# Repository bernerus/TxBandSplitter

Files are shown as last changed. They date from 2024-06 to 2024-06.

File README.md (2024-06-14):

# TxBandSplitter
SDR Transmit band splitter and amplifier for VHF/UHF bands. A KiCad + Python project.

The aim of this project is to create an intermediate transmit driver stage that 
takes the RF level of an SDR transmitter from around 1 dBm to around +30 dBm.
Doing this would probably be illegal except for licensed radio amateurs, but
such equipment should nevertheless work only on the amateur bands.
This device takes 1 dBm RF from e.g. a HackRF transceiver, splits the output on
either the 50, 144, 432 och 1295 MHz bands and takes the output level to about +30 dBm or 1 W.
The amplification is done in two steps with the filtering and a programmable attenuator in between,
The final RF is the again split on 4 outputs usein PIN diodes.

The band selection, amplifier power and level of attenuation is controlled over an I2C connection
suitable for connectiong to a RaspBerry PI computer.

Sample software for controlling the device from an RPI is written in Python.

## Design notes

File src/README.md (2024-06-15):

This is the code used for controlling the TxBandSplitter version 3. 

Note that the hardware published in this repo is version 4. 
This means that all definitions here relating to 
Points to review is the defs in p21_defs.py, the band switching codes and the band order for attenuation values.

The code will be reviewes at a later stage when v4 of the hardware 
has been physically realized and tested.

SM6FBQ 2024-06-15

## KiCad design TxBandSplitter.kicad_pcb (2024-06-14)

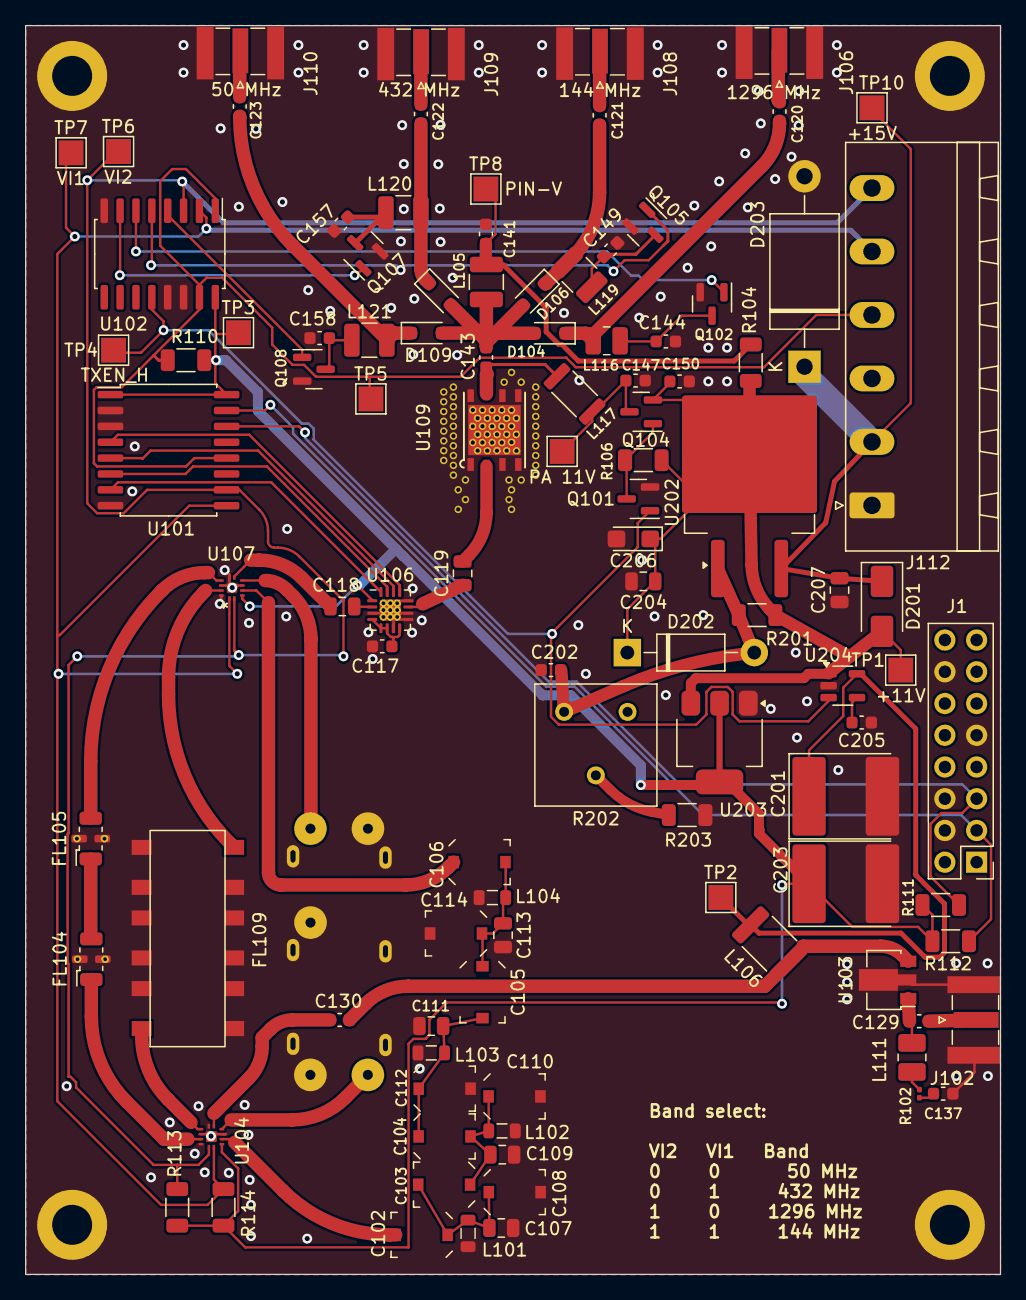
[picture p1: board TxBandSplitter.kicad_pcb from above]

Board: 2 copper layers, 78.0 x 99.9 mm, 109 parts (1 on the bottom side), 63 nets.

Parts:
C102, C106, C108, C110, C112, C114: 5-20pF; C_Trimmer_Murata_TZC3
C103, C104, C105: 2.5-6pF; C_Trimmer_Murata_TZC3
C107, C113: 100pF; C_0805_2012Metric
C109, C111: 120pF; C_0805_2012Metric
C117, C120, C121: 1nF; C_0603_1608Metric
C118, C119: 1nF; C_0805_2012Metric
C122, C123, C129, C130, C141, C143, C144, C147, C149, C150, C157, C158, C205: 10nF; C_0603_1608Metric
C137: 330pF; C_0603_1608Metric
C201: 2.2μF; CP_EIA-7260-38_AVX-R_Pad2.68x6.30mm_HandSolder
C202: 10μF; C_0603_1608Metric
C203: 10μF; CP_EIA-7260-38_AVX-R_Pad2.68x6.30mm_HandSolder
C204, C207: 0.1μF; C_0805_2012Metric
C206: 1μF 16V Tantal; CP_EIA-3216-18_Kemet-A
D104, D106, D107, D109: BA592; D_SOD-323_HandSoldering
D201: LL4002; D_SMA
D202: LL4002; D_DO-41_SOD81_P10.16mm_Horizontal
D203: 1.5KE18A; D_DO-201AE_P15.24mm_Horizontal
FL101: FE-7H3-160A; FE-7H3-160
FL104: HFCN-1200+; Filter_Mini-Circuits_FV1206
FL105: LFCN-1325; Filter_Mini-Circuits_FV1206
FL109: FE-1069; 5CHT
H101, H102, H103, H104: MountingHole_Pad; MountingHole_3.2mm_M3_DIN965_Pad
J1: Raspberry_Pi 16-pin; PinHeader_2x08_P2.54mm_Vertical
J102, J106, J108, J109, J110: SMA; SMA_Samtec_SMA-J-P-X-ST-EM1_EdgeMount
J112: Conn_01x06_Pin; PhoenixContact_MSTBA_2,5_6-G-5,08_1x06_P5.08mm_Horizontal
L101, L102, L103, L104: 68 nH; L_0805_2012Metric
L105: 5.6uH; L_1210_3225Metric
L106, L117: WA8514-AE; L_1812_4532Metric
L111: 680nH; L_1008_2520Metric_Pad1.43x2.20mm_HandSolder
L116: 680 nH; L_1008_2520Metric
L119: 1.8uH; L_1210_3225Metric
L120: 5,6 uH; L_1210_3225Metric
L121: 15 uH; L_1210_3225Metric
Q101, Q102, Q105, Q107, Q108: BSS138; SOT-23
Q104: FDN358P; SOT-23
R102: 150; R_0201_0603Metric
R104: 270; R_1206_3216Metric
R106, R110, R111, R112, R113, R114: 10k; R_1206_3216Metric
R201, R203: 220; R_1206_3216Metric
R202: 1k; Potentiometer_Bourns_3386F_Vertical
TP1: +11V; TestPoint_Pad_2.0x2.0mm
TP2: VCC; TestPoint_Pad_2.0x2.0mm
TP3: VDD; TestPoint_Pad_2.0x2.0mm
TP4: TXEN_H; TestPoint_Pad_2.0x2.0mm
TP5: TXEN_L; TestPoint_Pad_2.0x2.0mm
TP6: VI2; TestPoint_Pad_2.0x2.0mm
TP7: VI1; TestPoint_Pad_2.0x2.0mm
TP8: PIN-V; TestPoint_Pad_2.0x2.0mm
TP9: PA 11V; TestPoint_Pad_2.0x2.0mm
TP10: +15V; TestPoint_Pad_2.0x2.0mm
U101: PCF8574; SOIC-16W_7.5x10.3mm_P1.27mm
U102: 4555; SO-16_5.3x10.2mm_P1.27mm
U103: PGA-103+; SOT-89-3
U104, U107: RFSW6042; QFN12_RFSW_QOR
U106: SKY12348-350LF; QFN-16-1EP_3x3mm_P0.5mm_EP1.7x1.7mm_ThermalVias
U109: PHA-202+; PHA202+
U202: LM317D2T; TO-263-2
U203: LD1117S33TR_SOT223; SOT-223-3_TabPin2
U204: LP2985-5.0; SOT-23-5

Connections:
+11V: C150.1, C204.1, C206.1, D201.2 (A), D202.1 (K), Q104.2 (S), R104.2, R106.1, R201.1, TP1.1, U202.2 (VO), U203.3 (VI), U204.1 (VIN)
/Power/+15V: C207.2, D201.1 (K), D203.1 (K), J112.2, TP10.1, U202.3 (VI)
/RF1: C130.1, L106.2, U103.3
/RFCIN: C130.2, U104.7 (ANT)
/RFOUT2: C121.2, D106.1 (K), L119.2
/RFOUT6: C123.2, D109.1 (K), L121.2
/RFOUT23: C120.2, D104.1 (K), L116.2
/RFOUT70: C122.2, D107.1 (K), L120.2
/RF_In: C129.1, J102.1 (In)
/RF_Out_2m: C121.1, J108.1 (In)
/RF_Out_6m: C123.1, J110.1 (In)
/RF_Out_23cm: C120.1, J106.1 (In)
/RF_Out_70cm: C122.1, J109.1 (In)
/SCL: J1.5 (SCL/GPIO3), R111.2, U101.14 (SCL)
/SDA: J1.3 (SDA/GPIO2), R112.2, U101.15 (SDA)
/TXEN_H: Q101.1 (G), TP4.1, U102.12 (Q0), U204.3 (ON/~OFF)
/TXEN_L: J112.4, R110.2, TP5.1, U101.12 (P7), U102.1 (~EN), U102.15 (~EN)
GND: C107.2, C108.2, C109.2, C110.2, C111.2, C112.2, C113.2, C114.2, C117.1, C137.2, C141.1, C144.1, C147.1, C149.1, C150.2, C157.1, C158.1, C201.2, C202.1, C203.2, C204.2, C205.1, C206.2, C207.1, D203.2 (A), FL101.1 (IN-), FL101.3 (OUT-), FL101.GND (MID-), FL104.2 (GND), FL104.4 (GND), FL105.2 (GND), FL105.4 (GND), FL109.2 (GND), FL109.8 (GND), FL109.GND, H101.1, H102.1, H103.1, H104.1, J1.4 (GND), J1.6 (GND), J1.9 (GND), J1.14 (GND), J102.2 (Ext), J106.2 (Ext), J108.2 (Ext), J109.2 (Ext), J110.2 (Ext), J112.1, L101.2, L102.2, L103.2, L104.2, Q101.2 (S), Q102.2 (S), Q105.2 (S), Q107.2 (S), Q108.2 (S), R203.2, U101.2 (A1), U101.3 (A2), U101.8 (VSS), U102.8 (Vss), U102.13 (A1), U102.14 (A0), U103.2 (GND), U104.5 (GND), U104.8 (GND), U104.10 (GND), U104.12 (GND), U104.13 (EPAD), U106.3 (NC), U106.7 (NC), U106.9 (NC), U106.10 (NC), U106.12 (NC), U106.17 (GND), U107.5 (GND), U107.8 (GND), U107.10 (GND), U107.12 (GND), U107.13 (EPAD), U109.EP, U109.GND, U203.1 (GND), U204.2 (GND)
unnamed: C102.1, C103.2, C107.1, C108.1, L101.1
unnamed: C103.1, C104.2, C109.1, C110.1, L102.1
unnamed: C104.1, C105.2, C111.1, C112.1, L103.1
unnamed: C105.1, C106.2, C113.1, C114.1, L104.1
unnamed: C129.2, L111.1, U103.1
unnamed: C137.1, R102.2
unnamed: C141.2, L105.2, R104.1, TP8.1
unnamed: C143.2, D104.2 (A), D106.2 (A), D107.2 (A), D109.2 (A), L105.1
unnamed: C202.2, D202.2 (A), R201.2, R202.1, U202.1 (ADJ)
unnamed: FL101.5 (IN+), U107.6 (RF3)
unnamed: FL101.2 (OUT+), U104.6 (RF3)
unnamed: FL104.1 (IN), U104.11 (RF2)
unnamed: FL104.3 (OUT), FL105.1 (IN)
unnamed: FL105.3 (OUT), U107.9 (RF1)
unnamed: FL109.1 (IN), U104.9 (RF1)
unnamed: FL109.7 (OUT), U107.11 (RF2)
unnamed: L111.2, R102.1
unnamed: Q101.3 (D), Q104.1 (G), R106.2
unnamed: C144.2, L116.1, Q102.3 (D)
unnamed: Q102.1 (G), U102.6 (Q2)
unnamed: C147.2, L117.1, Q104.3 (D), TP9.1
unnamed: C149.2, L119.1, Q105.3 (D)
unnamed: Q105.1 (G), U102.5 (Q1)
unnamed: C157.2, L120.1, Q107.3 (D)
unnamed: Q107.1 (G), U102.7 (Q3)
unnamed: C158.2, L121.1, Q108.3 (D)
unnamed: Q108.1 (G), U102.4 (Q0)
unnamed: R202.2, R203.1
unnamed: U101.4 (P0), U106.13 (V1)
unnamed: U101.5 (P1), U106.14 (V2)
unnamed: U101.6 (P2), U106.15 (V3)
unnamed: U101.7 (P3), U106.16 (V4)
unnamed: C102.2, U104.4 (RF4)
unnamed: C118.2, U106.2 (RF1)
unnamed: C119.1, U106.11 (RF2)
unnamed: C117.2, U106.4 (RFGND1), U106.5 (RFGND2), U106.6 (RFGND3), U106.8 (RFGND4)
unnamed: C118.1, U107.7 (ANT)
unnamed: C106.1, U107.4 (RF4)
unnamed: C143.1, L117.2, U109.OUT (RF_OUT)
unnamed: C205.2, U204.4 (BP)
RF_Filtered: C119.2, U109.IN (RF_IN)
VCC: C201.1, L106.1, TP2.1, U204.5 (VOUT)
VDD: C203.1, R110.1, R111.1, R112.1, R113.1, R114.1, TP3.1, U101.1 (A0), U101.16 (VDD), U102.16 (Vdd), U104.3 (VDD), U106.1 (VDD), U107.3 (VDD), U203.2 (VO)
VI1: J112.5, R114.2, TP7.1, U101.9 (P4), U102.2 (A0), U104.2 (C1), U107.1 (C2)
VI2: J112.6, R113.2, TP6.1, U101.10 (P5), U102.3 (A1), U104.1 (C2), U107.2 (C1)

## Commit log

2024-06-14 Initial commit representing version 4 of this project
    [TxBandSplitter-B_Cu.gbl, TxBandSplitter-B_Cu.gbr, TxBandSplitter-B_Mask.gbr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]
2024-06-15 Added python code and appropriate .gitignores
    [power.kicad_sch]
2024-06-15 Changed name of power schematic
    [TxBandSplitter.kicad_sch, power.kicad_sch]
